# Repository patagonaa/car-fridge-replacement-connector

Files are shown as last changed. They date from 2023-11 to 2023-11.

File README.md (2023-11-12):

# HCalory PowerPole Connector replacement
3D printable part to replace the panelmount DC connector with Anderson PowerPole plugs for the Hcalory EC30 portable/car fridge, as the connector on mine had melted ([see picture below](#original-melty-connector)).

The original connector is a misuse of the IEC (AC) connector C11/C12, which a lot of portable fridge manufacturers seem to use on their devices. This replacement fits the original hole in the panel and replaces the C12 connector with an Anderson PowerPole PP15/30/45.

Be aware, **the original connector has an integrated fuseholder, so a fuse has to be added between the PowerPole connector and the internal connections** to avoid risk of fire and other damage to the device!
The design could easily be adapted to fit a fuse holder as there is a lot of space, but I didn't do that as I didn't have one on hand.

### OpenSCAD model
The part is put together from the cover plate and the extruded panel hole, from which the PowerPole Connector is subtracted. The part is then split in two printable parts, which are held together by both the connector and one of the mounting screws.

The `pp45()` module (with its associated variables) is probably useful for other projects which include PowerPole connectors as well.

## Pictures
### Model
The model is designed as one whole unit, which is then split into two printable parts that fit together.

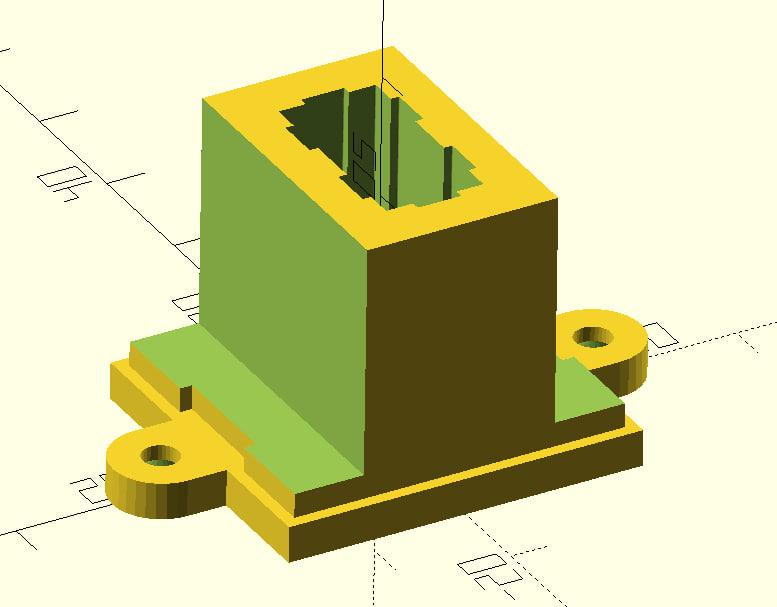
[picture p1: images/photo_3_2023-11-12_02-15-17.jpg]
Entire Model


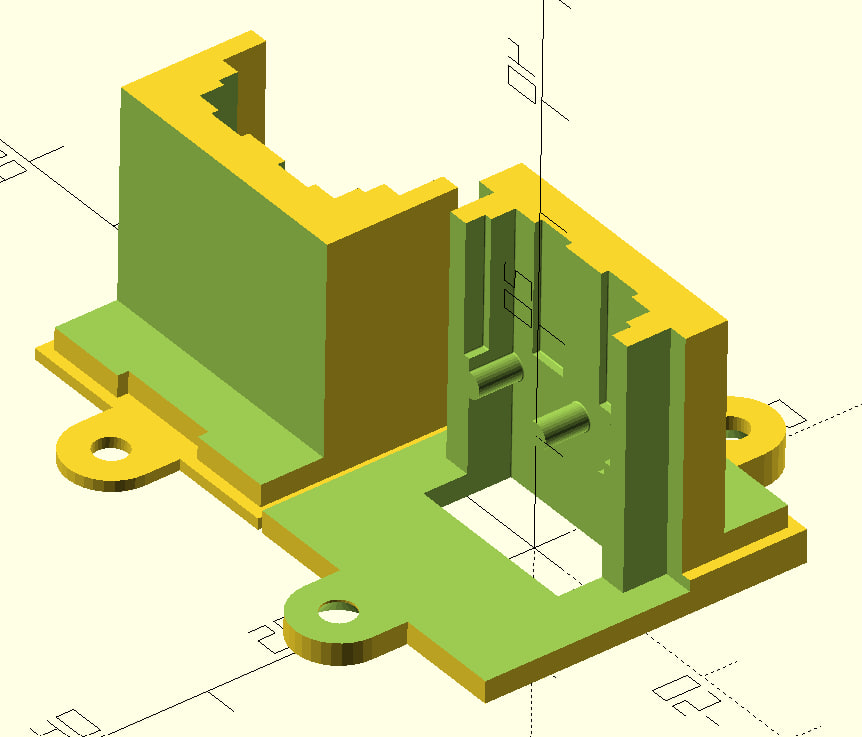
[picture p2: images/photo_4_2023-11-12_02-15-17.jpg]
Model split into printable parts


### Sliced Model
This was sliced with PrusaSlicer with the supports for the outer PowerPole peg holes removed on both halves (as they aren't needed) so only the center support stays.

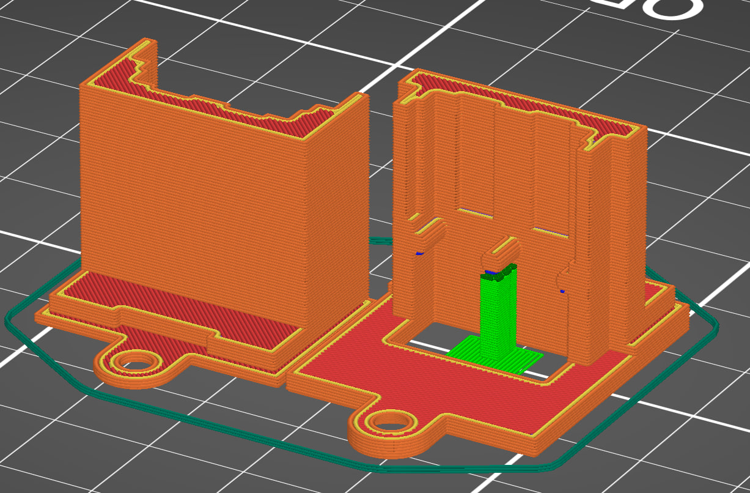
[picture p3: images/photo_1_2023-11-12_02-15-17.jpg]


### Print

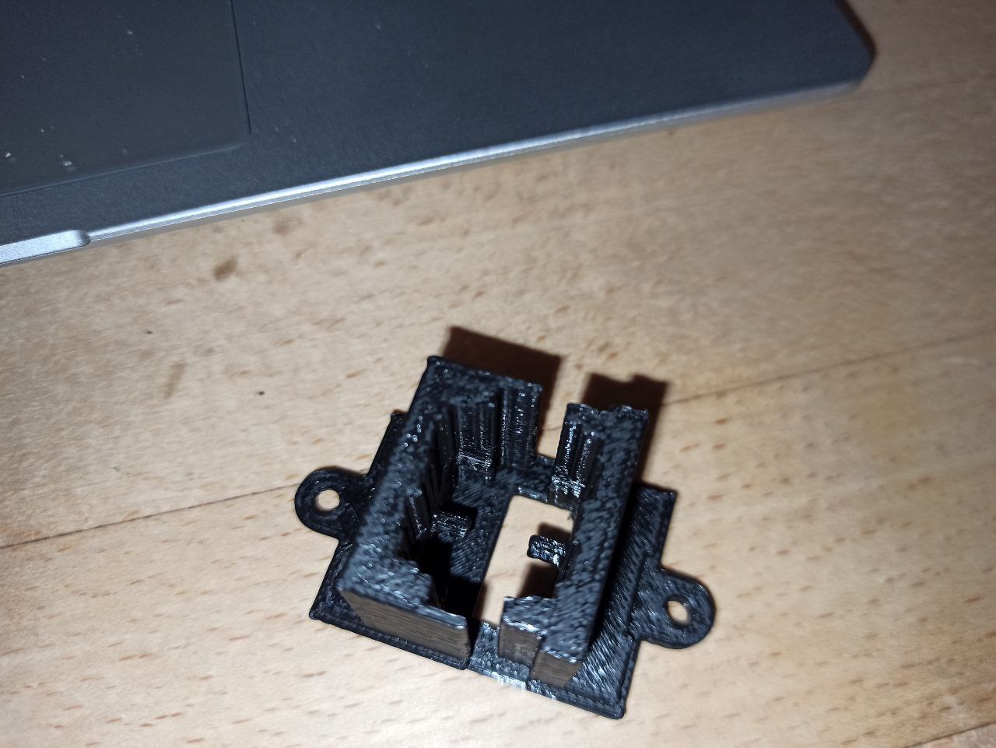
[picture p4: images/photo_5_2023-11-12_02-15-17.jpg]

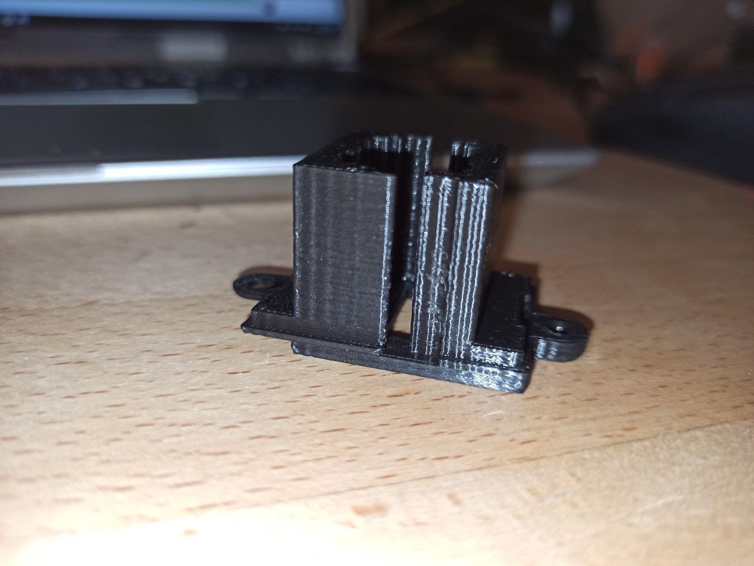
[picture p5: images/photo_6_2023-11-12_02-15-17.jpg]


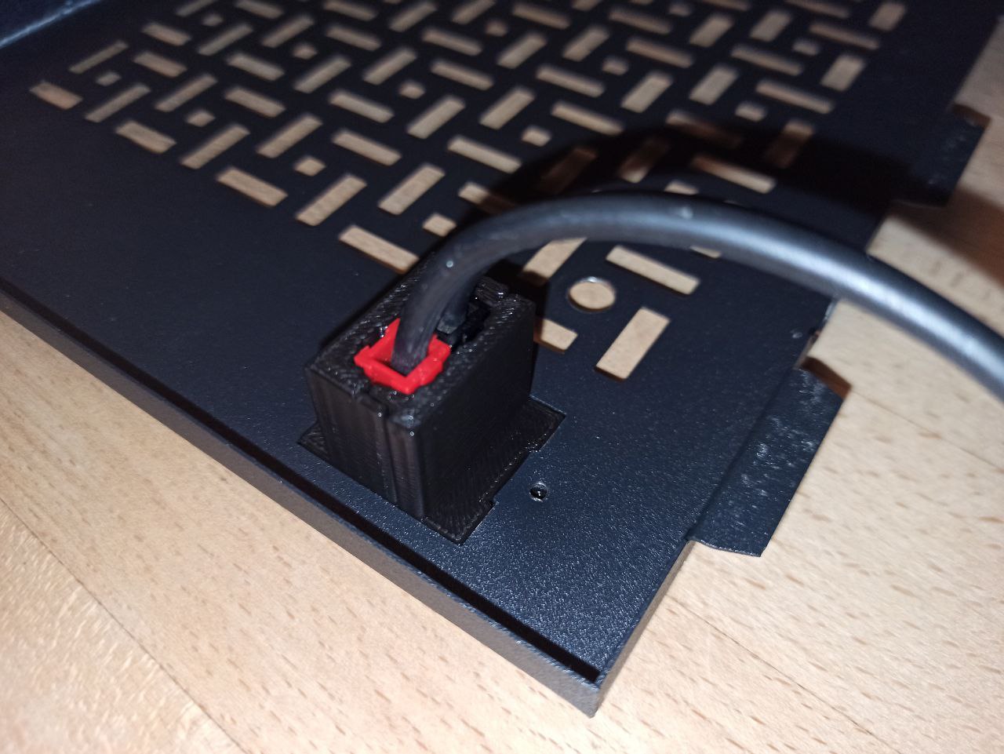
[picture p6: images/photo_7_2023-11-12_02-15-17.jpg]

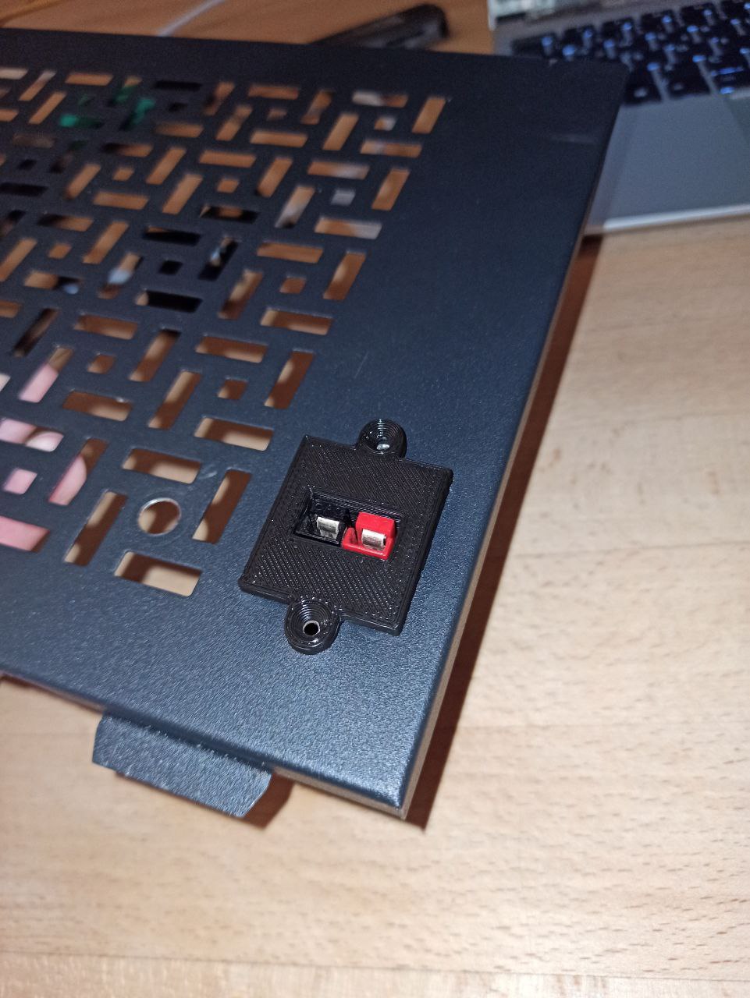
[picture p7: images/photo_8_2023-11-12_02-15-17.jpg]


### 

### Original (melty) connector
Here, the plastic around the positive pin of the socket has melted, likely due to bad contact resistance. The pin on the plug side has melted as well.

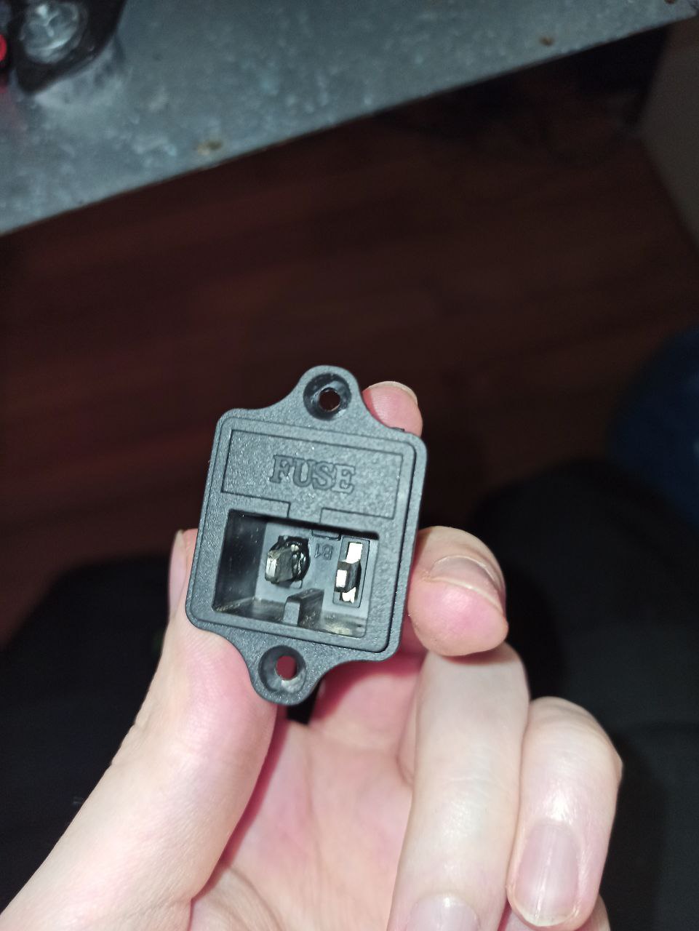
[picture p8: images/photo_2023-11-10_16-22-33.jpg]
Original connector


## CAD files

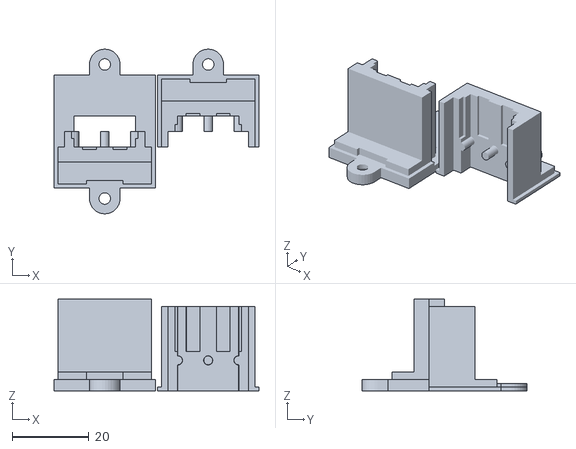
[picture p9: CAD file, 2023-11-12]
fridge-replacement-connector.stl
53.5 x 43.0 x 24.0

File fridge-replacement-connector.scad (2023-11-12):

$fn = $preview ? 16 : 32;

// General
intersectMargin=0.01;

pp45Tolerance = 0.1; // extra space in all dimensions for PowerPole to fit

// Panel Hole
holeWidth = 24.5;
holeHeightInner = 25.5;
tabHeight = 1;
tabWidth = 9.5;
flangeSize = 8;

holeHeightOuter = holeHeightInner + 2*tabHeight;

// Front Plate
coverPlateWidth = holeWidth + 2;
coverPlateHeight = holeHeightOuter + 2;
coverPlateThickness = 3;

screwHoleDistance = 35;
screwHoleDiameter = 3;

// PowerPole
ppSize = 7.9;
ppLength = 24.6;

retentionPinDiameter = 2.5;
retentionPinPosition = 10;

tongueHeight = 0.7;
tongueWidth = 3.4;
tongueLength = 12.2;

// ----

module holeShape(){
    module halfPlate(){
        difference(){
            square([holeWidth, holeHeightOuter/2]);
            translate([holeWidth/2 - (tabWidth/2), holeHeightOuter/2-tabHeight]){square([tabWidth, tabHeight]);};
        }
    }
    translate([-holeWidth/2,0]){
        halfPlate();
        mirror([0,1,0]){halfPlate();};
    }
}

module coverPlate(){
    
    module flange(){
        straightPartLength = 6;
        translate([coverPlateWidth/2, screwHoleDistance/2]){
            circle(d=flangeSize);
            translate([-flangeSize/2, -straightPartLength])
                square([flangeSize, straightPartLength]);
        }
    }
    
    module halfPlateShape() {
        difference(){
            union(){
                square([coverPlateWidth, coverPlateHeight/2]); // main square
                flange();
            };
            translate([coverPlateWidth/2, screwHoleDistance/2])
                circle(d=screwHoleDiameter);
        };
    };
    
    module halfPlate() {
        difference(){
            linear_extrude(coverPlateThickness){
                halfPlateShape();
            }
            translate([coverPlateWidth/2, screwHoleDistance/2, -intersectMargin]) cylinder(1.8, 3, 1.5); // countersink hole
        }
    }

    translate([-coverPlateWidth/2, 0]){
        halfPlate();
        mirror([0, 1, 0]){
            halfPlate();
        }
    }
}

module pp45(){
    module pin(){
        translate([0,(ppSize+intersectMargin)/2,0])
            rotate([90,0,0])
            cylinder(h=ppSize+intersectMargin,d=retentionPinDiameter);
    }
    
    module tongue(){
        translate([-tongueWidth/2,ppSize/2-intersectMargin, ppLength-tongueLength])
            cube([tongueWidth, tongueHeight, tongueLength]);
    }

    difference(){
        union(){
            translate([-ppSize/2, -ppSize/2, 0])
                cube([ppSize, ppSize, ppLength]);
            
            for(i = [0:90:270]){
                rotate([0,0,i]) tongue();
            }
        };
        translate([ppSize/2,0,retentionPinPosition])
            pin();
        translate([-ppSize/2,0,retentionPinPosition])
            pin();
    }
}



//pp45();


module part(){
    difference(){
        union(){
            coverPlate();

            translate([0,0,coverPlateThickness])
            {
                linear_extrude(21){ // connector housing
                    holeShape();
                };
            }
        };
        //remove some unnecessary material from connector housing to save filament/print time
        translate([-20,8,5]) cube([40,20,50]);
        translate([-20,-27.9,5]) cube([40,20,50]);
        
        // add hole for pp45 connector with some extra room so the connector can be fitted well
        minkowski(){
            translate([-7.9/2, 0, -intersectMargin]){
                pp45();
                translate([7.9-intersectMargin,0,0]) pp45();
            };
            sphere(r=pp45Tolerance);
        };
    }
}

module splitShape(){ // the shape by which the two parts of the model are split so it can be snapped together around the connector
    translate([-15,0,2]) cube([30,25,40]);
    module key(){
        translate([10.5, -4,2]) linear_extrude(40){
            square([4,4+intersectMargin]);
        };
    }
    key();
    mirror([1,0,0]) key();
}


if ($preview) {
    part();
    color("red", 0.2)
        splitShape();
}else{
    difference(){
        part();
        splitShape();
    };

    translate([27, 0, -2]){
        intersection(){
            part();
            splitShape();
        };
    }
}

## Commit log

2023-11-12 rename PP "clip" to "tongue", update README
    [fridge-replacement-connector.scad]
2023-11-12 add stl
    [fridge-replacement-connector.stl]
